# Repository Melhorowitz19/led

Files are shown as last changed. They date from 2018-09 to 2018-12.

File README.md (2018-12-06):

# Usage Notes

Pressing the button on the top of the device changes the state of the LED.
- 0: OFF
- 1: BRIGHT
- 2: INTERMEDIATE
- 3: DIM
- 4: 2 HZ FLASHING

In order to conserve battery, the battery is unattached while the device is not in use. In order to turn ON, remove the lid, attach the 9 V battery to the clip, and place flat in the empty compartment.

### ECAD Changes

While testing, some changes had to be made to the PCB post-photoetching. In particular, R2 and R4 were removed, and the button was attached directly to pin 4 of the ATMega, bypassing the Zener diode. These two resistors caused voltage division that caused the microcontroller to not register the button pressing.

### Lid/CAD Notes

The lid does not fit entirely within the box, but the fit is tight enough that it remains despite not being perfect. This lid was chosen for the final product in order to minimize the risk of collisions between the PCB components in the lid while keeping a tight fit for the battery. In order to add extra security, tape can be added to the lid (though it is not needed). A future iteration of the lid was created in SolidWorks (which can be seen in the Mechanical directory) that allows more space and a tighter fit if desired.

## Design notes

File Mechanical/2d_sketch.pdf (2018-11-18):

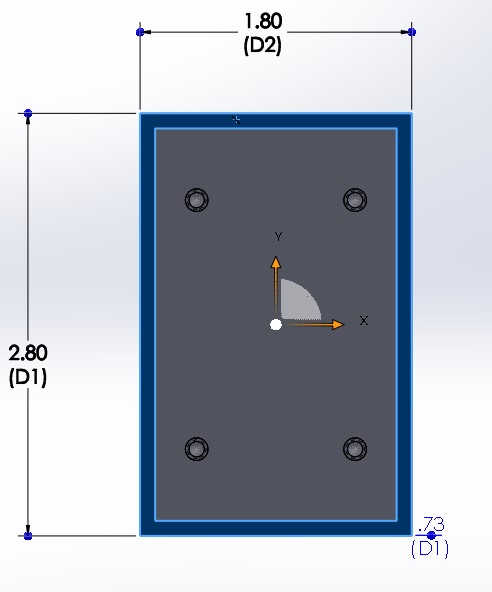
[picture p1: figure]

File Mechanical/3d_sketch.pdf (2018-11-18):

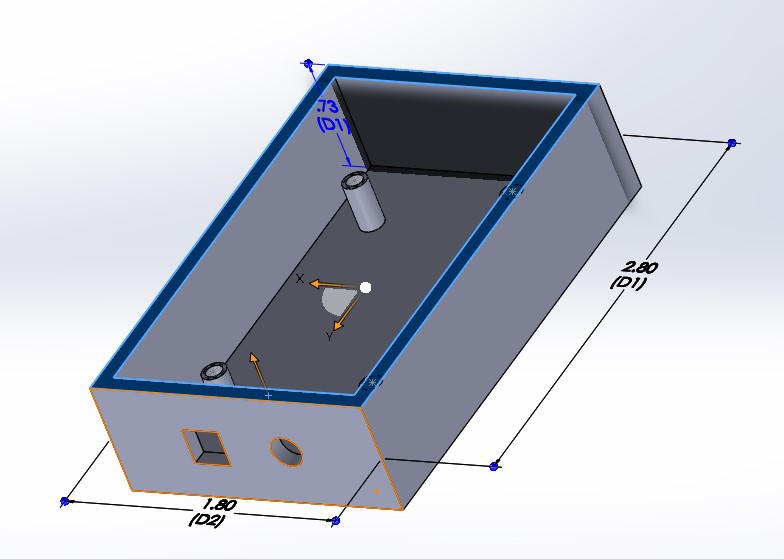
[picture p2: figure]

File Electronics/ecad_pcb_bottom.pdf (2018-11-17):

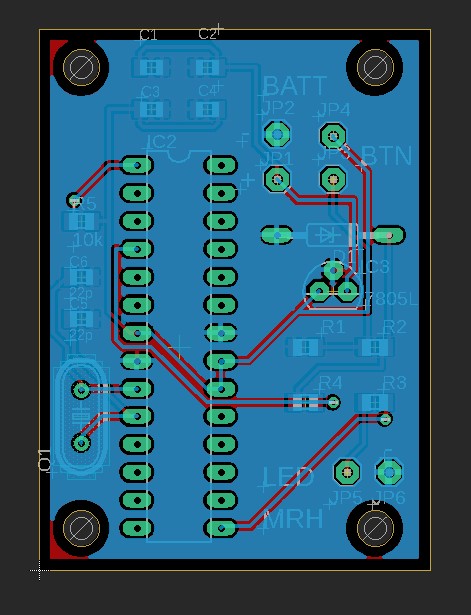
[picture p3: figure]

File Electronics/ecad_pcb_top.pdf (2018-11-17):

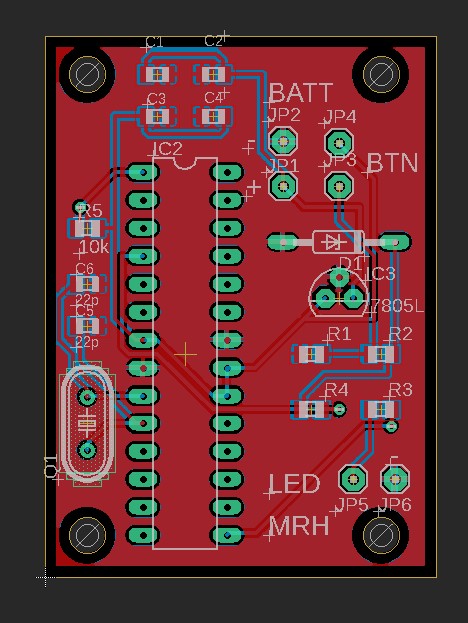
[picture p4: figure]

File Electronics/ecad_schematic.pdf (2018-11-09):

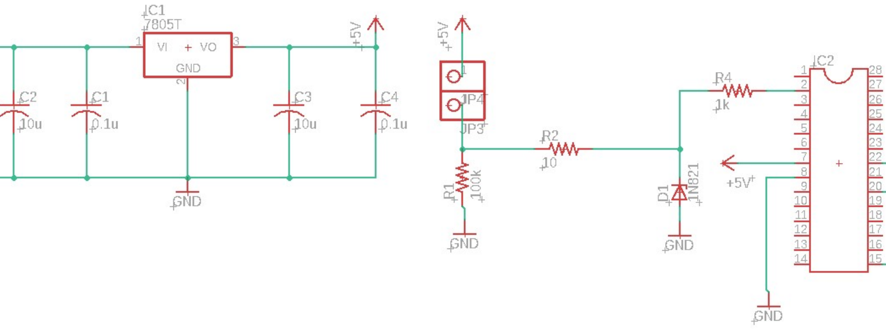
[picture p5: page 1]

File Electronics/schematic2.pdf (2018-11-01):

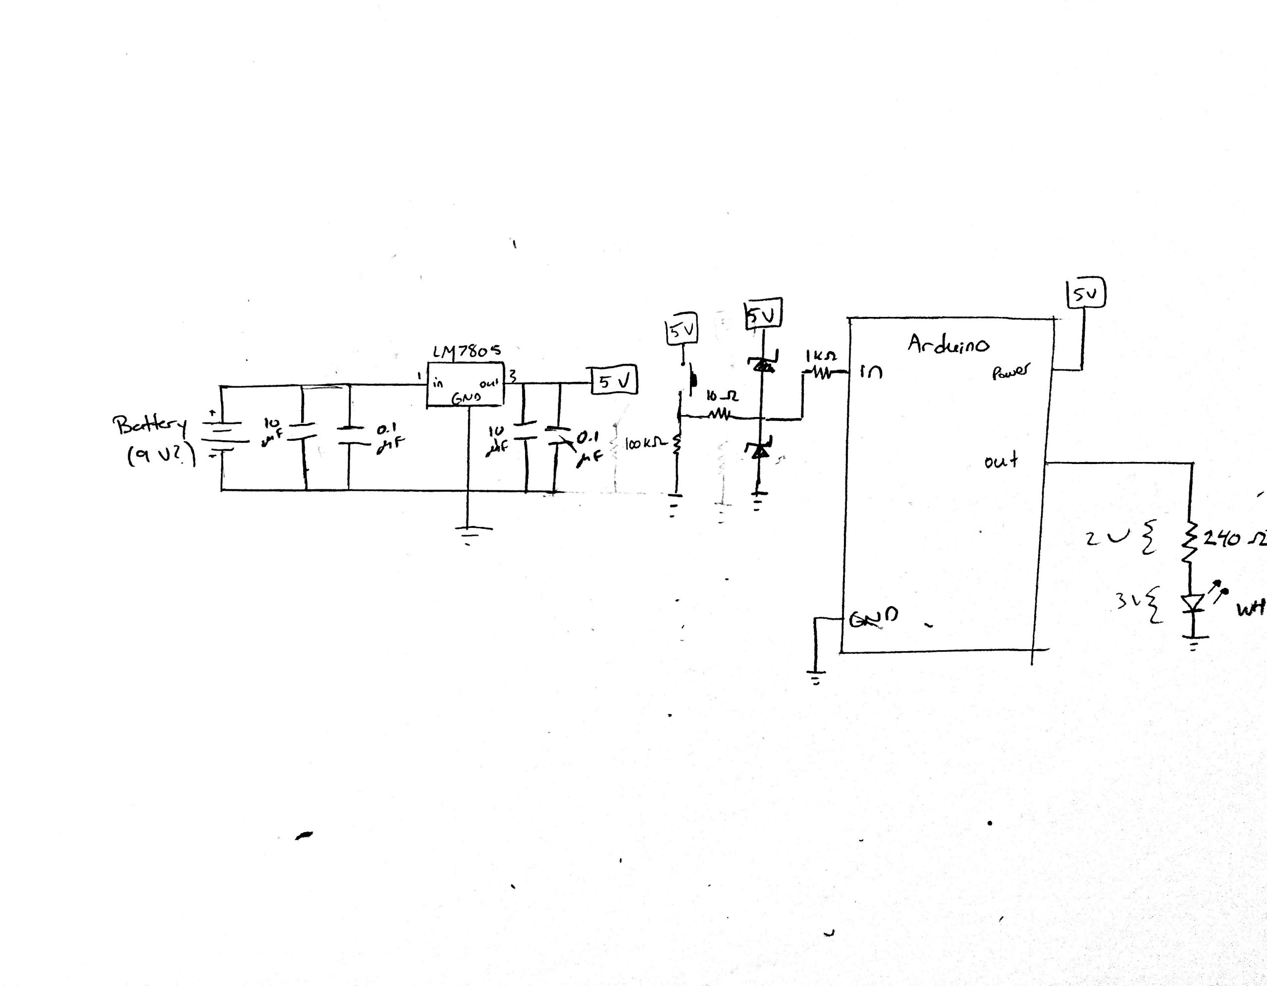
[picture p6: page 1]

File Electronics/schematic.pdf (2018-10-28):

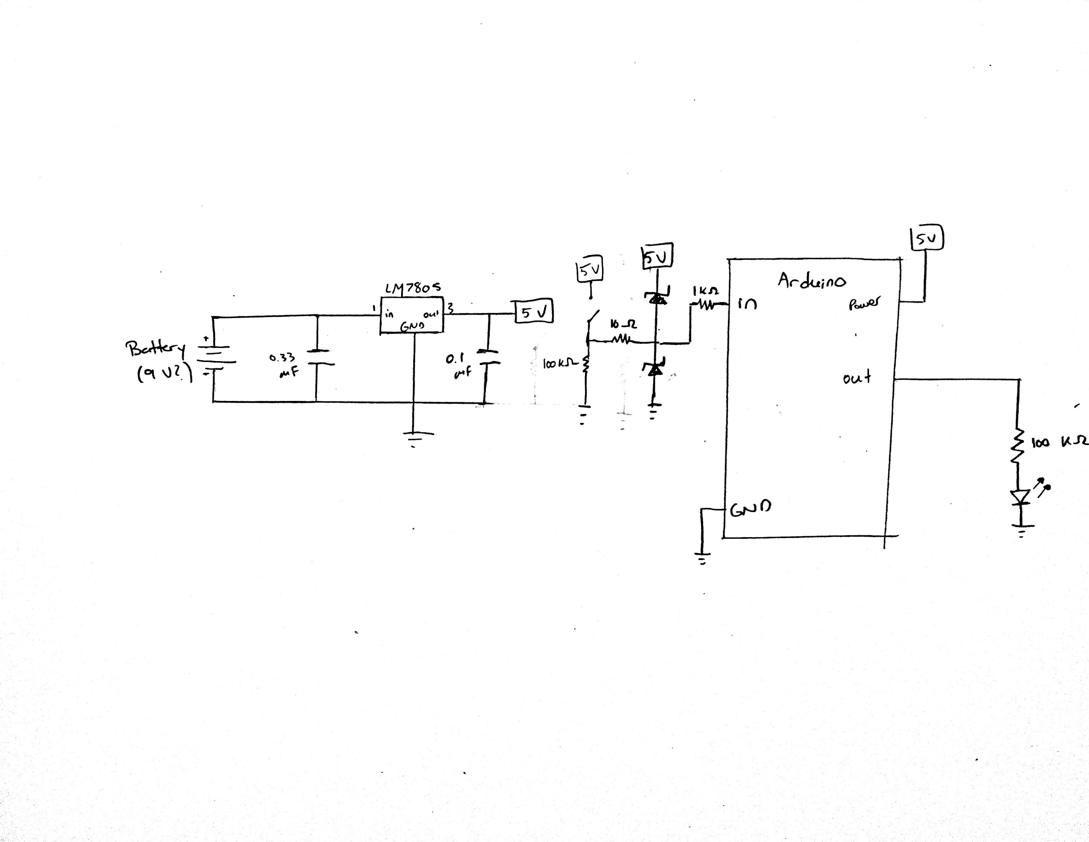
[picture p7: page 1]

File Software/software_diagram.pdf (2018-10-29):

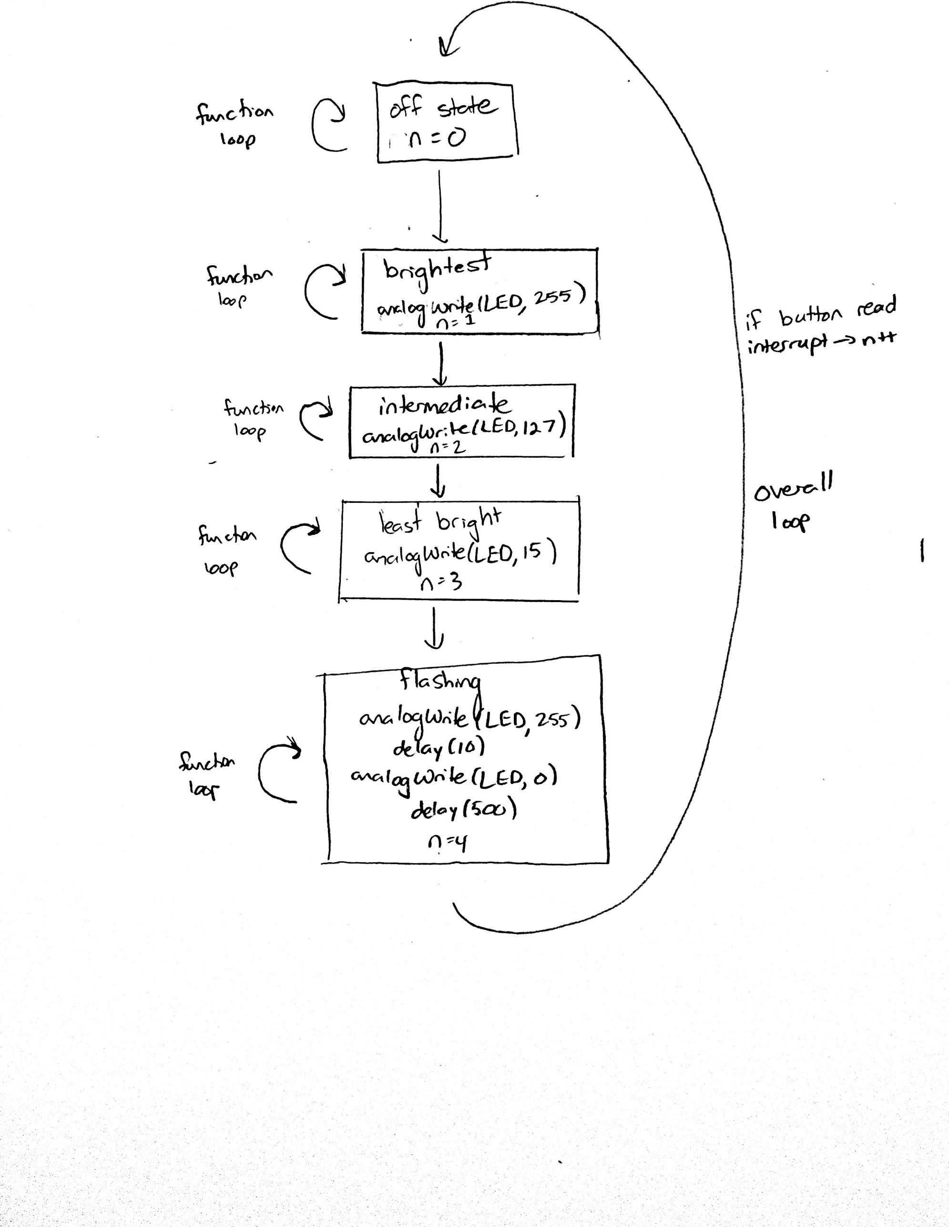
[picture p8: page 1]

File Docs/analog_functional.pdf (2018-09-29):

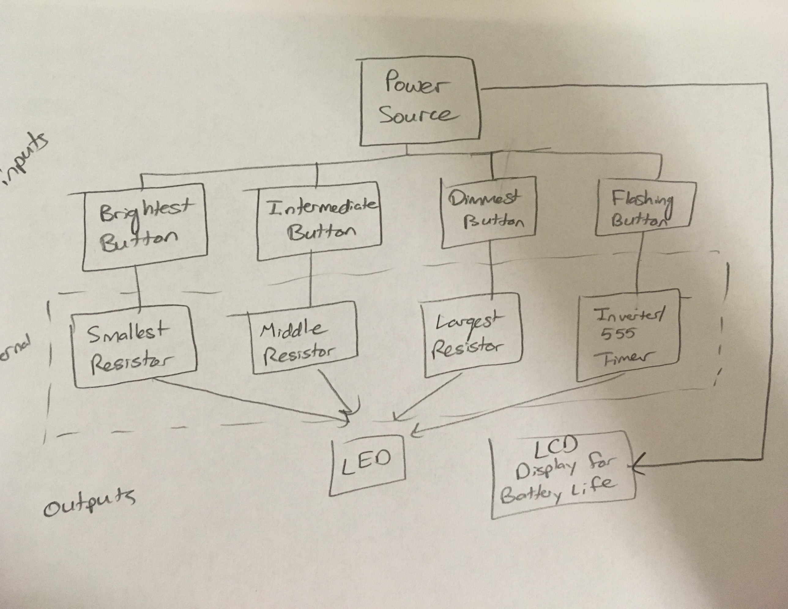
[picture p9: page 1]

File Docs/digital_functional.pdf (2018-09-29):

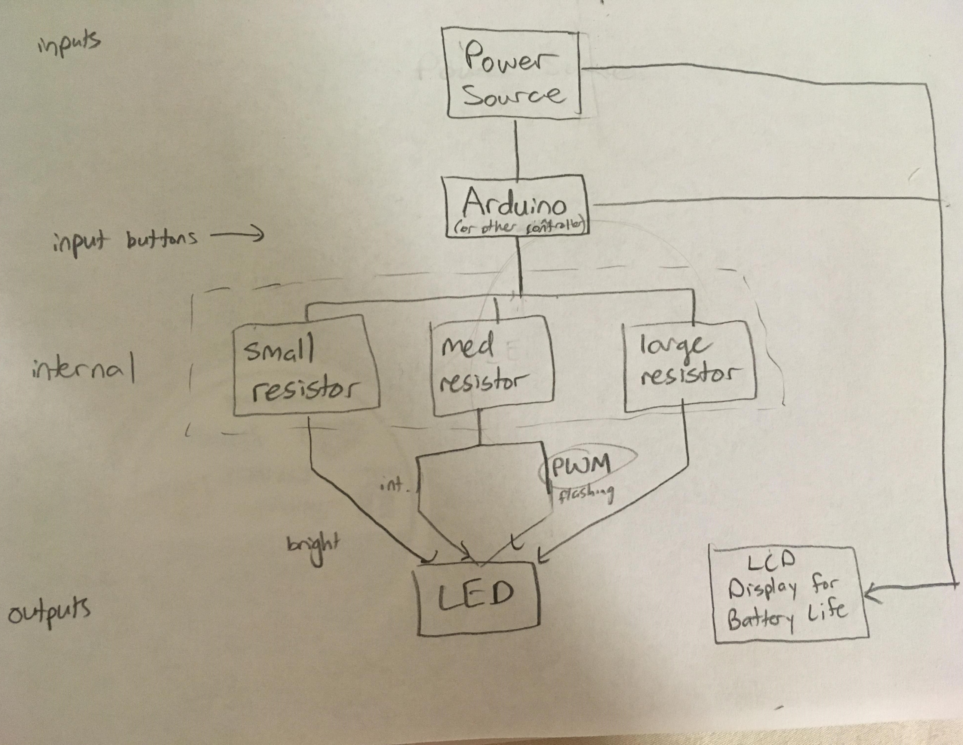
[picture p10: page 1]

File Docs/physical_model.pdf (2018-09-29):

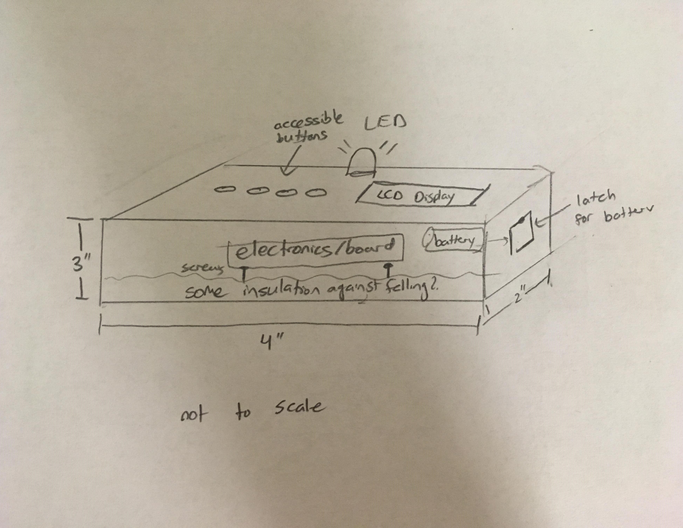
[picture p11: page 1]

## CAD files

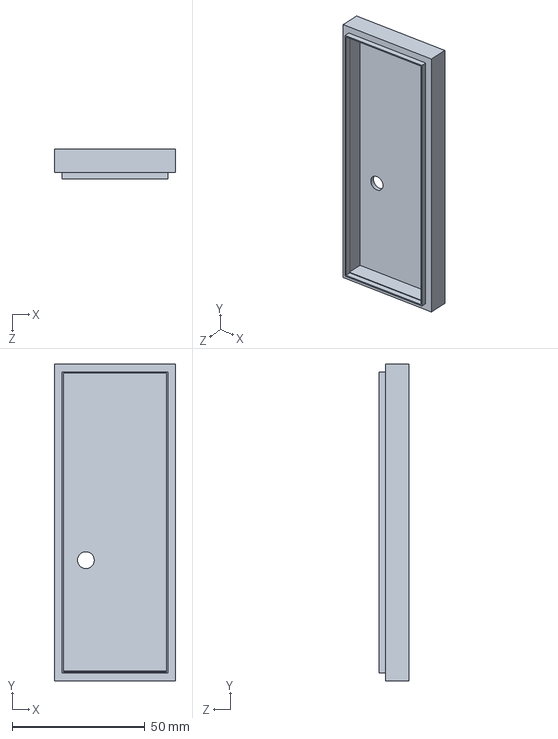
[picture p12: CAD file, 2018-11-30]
Mechanical/led_box_lid.SLDPRT
45.7 x 119.4 x 11.4 mm

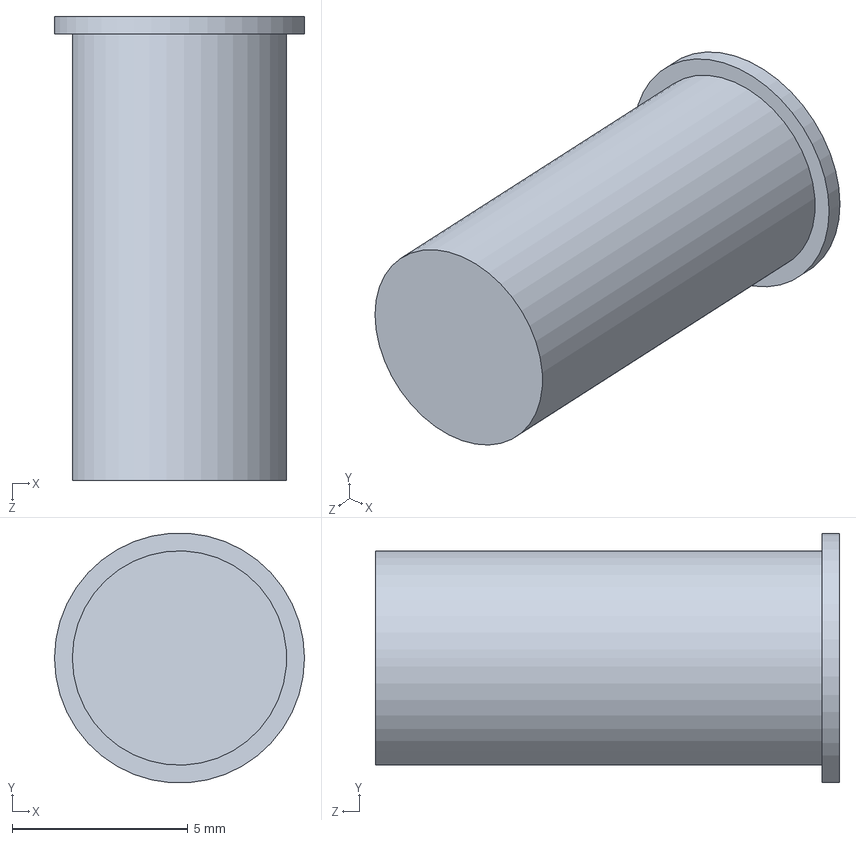
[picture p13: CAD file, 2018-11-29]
Mechanical/led_box_button.SLDPRT
7.11 x 7.09 x 13.2 mm

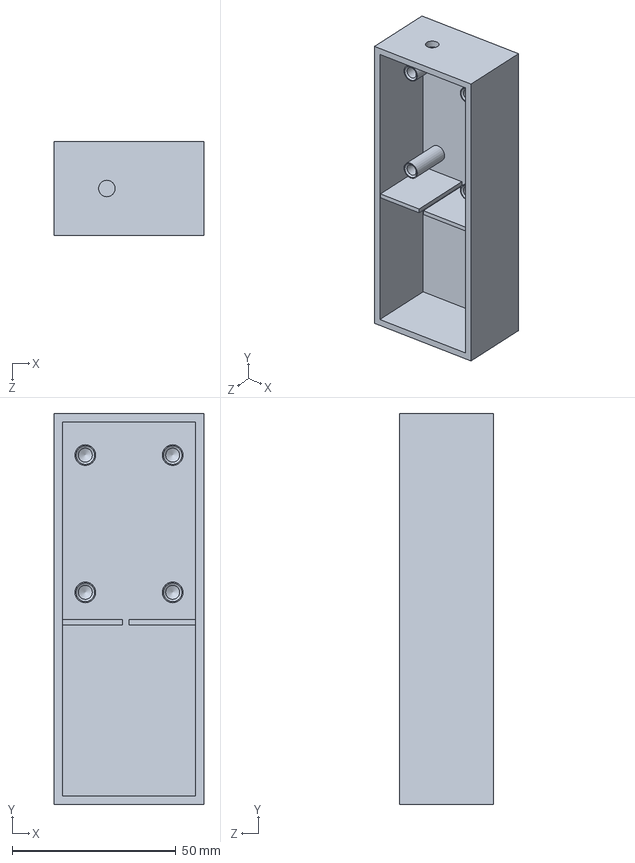
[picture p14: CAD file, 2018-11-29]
Mechanical/led_box_cad.SLDPRT
45.7 x 119.4 x 28.8 mm

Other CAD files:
Mechanical/led_box_lid2.STL
Mechanical/led_box_cad2.STL
Mechanical/led_box_button.STL
Mechanical/led_box_cad.STL
Mechanical/led_box_lid.STL

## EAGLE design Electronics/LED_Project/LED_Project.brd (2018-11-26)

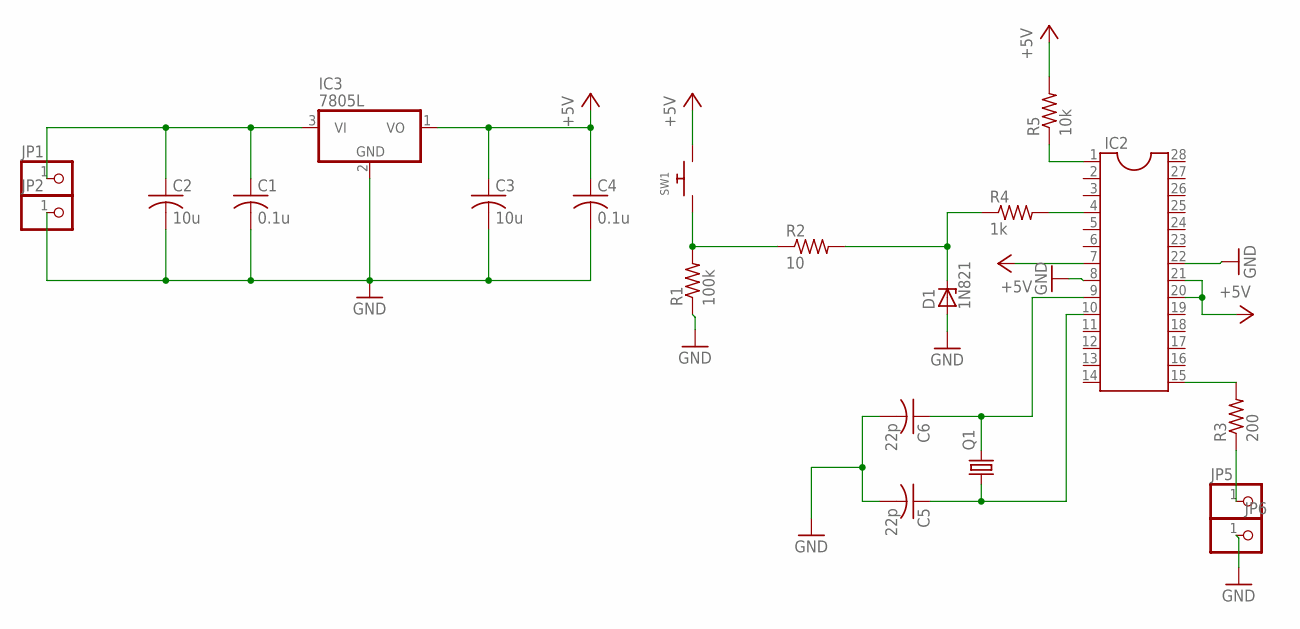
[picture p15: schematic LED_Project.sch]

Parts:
C1, C4: 0.1u; C0805K
C2, C3: 10u; C0805K
C5, C6: 22p; C0805K
D1: 1N821; DO35Z10
IC2: DIL28-3
IC3: 7805L; TO92
JP1, JP2, JP5, JP6: PINHD-1X1; 1X01
Q1: CRYSTALHC49S; HC49/S
R1: 100k; R0805
R2: 10; R0805
R3: 200; R0805
R4: 1k; R0805
R5: 10k; R0805
SW1: SWITCH_PUSHBUTTONSOFTTOUCHSMD_SJ; PUSHBUTTON_SMD_SJ

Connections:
+5V: C3.1, C4.1, IC2.7, IC2.20, IC2.21, IC3.1 (VO), R5.2, SW1.P$2
GND: C1.2, C2.2, C3.2, C4.2, C5.2, C6.2, D1.A, IC2.8, IC2.22, IC3.2 (GND), JP2.1, JP6.1, R1.1
unnamed: C1.1, C2.1, IC3.3 (VI), JP1.1
unnamed: R1.2, R2.1, SW1.P$1
unnamed: IC2.4, R4.2
unnamed: C6.1, IC2.9, Q1.2
unnamed: D1.C, R2.2, R4.1
unnamed: IC2.15, R3.2
unnamed: JP5.1, R3.1
unnamed: C5.1, IC2.10, Q1.1
unnamed: IC2.1, R5.1

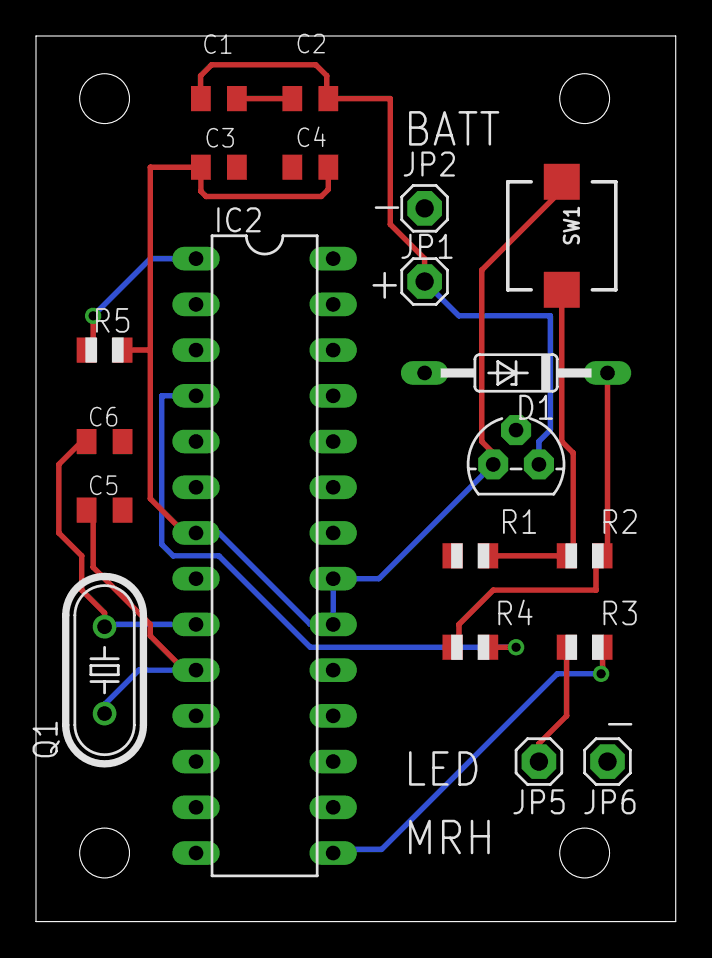
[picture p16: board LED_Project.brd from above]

Board: 2 copper layers, 35.5 x 49.2 mm, 20 parts (0 on the bottom side), 11 nets.

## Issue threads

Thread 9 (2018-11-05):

Schematic/Software Comments

Melhorowitz19, 2018-11-05:
There is a second version of my schematic and only one version of the software flowchart which are my final versions. Thank you!

mlp6, 2018-11-05:
Schematic looks good... diodes for voltage protection will need some specification (assuming you want Zener diodes with specified breakdown voltages).

W/r to the software flowchart, I'm not sure what you are referring to with "sub-loops" of the different brightness modes.  Insights?

Melhorowitz19, 2018-11-06:
Right now I just have Schottkey diodes in place. I looked it up for a while last night but I'm still a bit confused: is it necessary for Schottkey diodes in that configuration to have the 5 V forward voltage as well? Or would it be better to just have that single 5 V Zener diode across the input (though I had trouble finding a diode with a specific forward voltage last night)?

Also, would it be possible to just attach the ATMega from Arduino directly to the PCB, instead of using header pins to reduce weight?

For the flow-chart, the sub-loops were just to signify that it was staying in that operating mode until it was changed by a button pressed; I already uploaded my code and clarified that a bit more.

Thank you!

mlp6, 2018-11-08:
I think that a single Zener would be fine.

Yes, you can just attach the chip... that comes with some additional overhead, and I would recommend attaching it with a female socket so that you can easily remove / replace it instead of having to desolder all of those pins!

Code is looking good!

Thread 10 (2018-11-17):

ECAD Review

Melhorowitz19, 2018-11-17:
I realized I forgot to assign the issue for the ECAD review, sorry.

Thank you!

sphaerobolus, 2018-11-17:
No crystal. If you're using the internal RC clock, you're probably good. If you aren't using the internal RC, you'll want to figure out a clock.

JP3, JP4, JP5, JP6 look good on the board, but a more efficient way of getting this footprint would be to use a header. These are in libraries you already have. Also, would be good to label these in such a way that the reader knows what component goes there. It won't always be obvious that 3/4 are your switch and 5/6 are your LED.

I'm not sure what you're doing with the 3 resistors on the switch / IC2, pin2. Looks like you're going for a pull-down. Is this a configuration I haven't seen before?

The board layout looks good.

Melhorowitz19, 2018-11-17:
Thank you! I am using a pull-down configuration with the Zener diode, and the resistors are for pin voltage protection. If I have R1, are R2 and R4 not necessary then?

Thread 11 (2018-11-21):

Milestone 05

ps178, 2018-11-21:
Please create milestone issues for review

Your CAD is looking good. A few notes:
- I assume you are in the process of creating a lid for your casing.
- Dont forget you will need to include a battery to power your system. You need to consider that in your CAD design. You want the user to be able to access and change the battery.
- I notice that you have holes on the side of your casing. Are you going to bend the LED from where its soldered on the PCB board to have it go through the hole?

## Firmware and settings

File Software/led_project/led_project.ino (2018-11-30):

#define LED 9
#define FLASH_RATE 2
#define BUTTON_PIN 2
#define PWM_MAX 255

//mode: 0-off, 1-bright, 2-mid, 3- dim, 4-flashing
int mode = 0;
int BUTTON_PUSHED = 0;
int PWM_OUT = 0;
int freq_delay = 0;
 static int last_interrupt_time = 0;

void setup() {
  Serial.begin(9600);
	pinMode(LED, OUTPUT);
  pinMode(BUTTON_PIN,INPUT);
	attachInterrupt(digitalPinToInterrupt(BUTTON_PIN), button_pushed, FALLING);
	freq_delay = 1000/FLASH_RATE;
}

void check_button_press(){
  if (BUTTON_PUSHED==1 && mode==4){
    mode = 0;
  }
  else if (BUTTON_PUSHED==1 && mode!=4){
    mode++;
  }
  BUTTON_PUSHED=0;
}

void shine_LED(int pwm){
  analogWrite(LED,pwm);
}

void button_pushed(){
  int interrupt_time = millis();
 if (interrupt_time - last_interrupt_time > 200)
 {
     BUTTON_PUSHED = 1;
 }
 last_interrupt_time = interrupt_time;
}

void flash_LED(int freq){
  analogWrite(LED,PWM_MAX);
  delay(10);
  analogWrite(LED,0);
  delay(freq);
}


void loop(){
	check_button_press();
	set_pwm(); //put switch case in here instead
	}

void set_pwm(){
	switch (mode){
		case 0:
			PWM_OUT =0;
			shine_LED(PWM_OUT);
     Serial.print("0");
     break;
		case 1:
			PWM_OUT = PWM_MAX;
			shine_LED(PWM_OUT);
     Serial.print("1");
     break;
		case 2:
			PWM_OUT = int(PWM_MAX/2);
			shine_LED(PWM_OUT);
     Serial.print("2");
     break;
		case 3:
			PWM_OUT = int(PWM_MAX/4);
			shine_LED(PWM_OUT);
     Serial.print("3");
     break;
		case 4:
			flash_LED(freq_delay);
      Serial.print("4");
      break;
}
}

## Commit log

2018-10-28 added first iteration of schematic
2018-11-01 updated version of schematic
2018-11-05 led arduino software v1
2018-11-09 all Eagle files for 1st CAD
    [LED_Project.brd, LED_Project.sch]
2018-11-17 version 2 of pcb design
    [LED_Project.brd, LED_Project.sch, led_box_cad.SLDPRT]
2018-11-18 added first version of cad
    [led_box_cad.SLDPRT]
2018-11-25 3D printed version of CAD
    [led_box_cad.SLDPRT, led_box_cad.STL]
2018-11-26 replacecd ECAD files
    [LED_Project.brd, LED_Project.sch]
2018-11-29 edited code
    [led_box_button.SLDPRT, led_box_button.STL, led_box_cad.SLDPRT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]
2018-11-30 video proof of functionality
    [led_box_lid.SLDPRT, led_box_lid2.STL]
